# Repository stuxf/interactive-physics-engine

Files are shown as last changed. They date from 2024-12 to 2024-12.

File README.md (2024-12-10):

# Interactive Physics Engine
Final project for Microprocessors (E155) at Harvey Mudd College

The website, and more media can be found at [interactive-physics-engine.netlify.app](https://interactive-physics-engine.netlify.app/).

Authored by https://github.com/Amigoyith and https://github.com/stuxf/

## FPGA

The code for our FPGA is included inside the [/FPGA](/fpga/) folder. The file structure is as seen there.

Some highlihgts are that the main (top-level) module can be found at [/FPGA/main.sv](/fpga/main.sv), the display driver can be found at [/FPGA/display.sv](/fpga/display.sv) and the physics engine can be found at [/FPGA/physics_engine.sv](/fpga/physics_engine.sv).

For the build process, we opted to use [APIO](https://github.com/FPGAwars/apio), an open source ecosystem for FPGA boards using the Yosys toolchain. This allowed us several advantages over Lattice Radiant, including much faster build times. APIO is designed to be very simple to install, the command is just the following:

```BASH
pip3 install apio
```

And this sets up everything you need.

One issue we ran into was that APIO does not support SystemVerilog. We ended up using [github.com/zachjs/sv2v](https://github.com/zachjs/sv2v), combined with APIO, which is why you'll actually see SystemVerilog files in our repository. So our process of uploading our code to our FPGA ended up looking something like this, converting all our SystemVerilog to one big Verilog file, before uploading it to our FPGA.

```BASH
sv2v *.sv > all.v
apio upload
```

## MCU

The code for our MCU is included inside the [/MCU](/MCU/) folder.

The code that describes the MCU's operation is included inside the [main.c](/MCU/main.c) file. The rest of the code is for interacting with our devices, and can be found in [lib](/MCU/lib/). Two of the new libs that we added were for communicating over I2C and with our MPU6050 controller, and their implementation can be found at [lib/MPU6050.c](/MCU/lib/MPU6050.c) and [lib/STM32L432KC_I2C.c](/MCU/lib/STM32L432KC_I2C.c)

## CAD

The CAD for our 3d printed parts is included inside the [/CAD](/CAD/) folder.

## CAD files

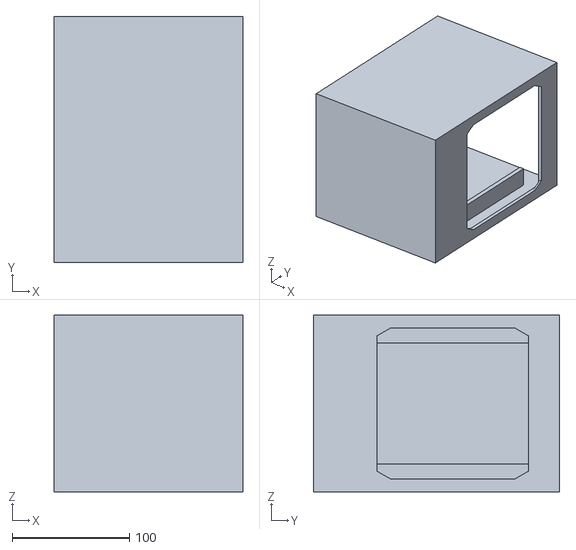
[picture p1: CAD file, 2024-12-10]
CAD/PhysicsEngineContainer.STL
161.0 x 210.0 x 151.0

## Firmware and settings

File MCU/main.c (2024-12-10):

/*
File: main.c
Author: Amy Liu
Email: amyliu01@g.hmc.edu
Date: 12/8/2024
Purpose: Handles all logic to send IMU data to FPGA
*/

#include "STM32L432KC.h"
#include "MPU6050.h"
#include <math.h>
#include <stdio.h>

void mcu_to_fpga(int16_t angle_deg);

int main(void) {

    configureFlash(); // Configure Flash memory for current clock settings.
    configureClock(); // Set up the system clock.
    RCC->APB1ENR1 |= RCC_APB1ENR1_TIM2EN; // Enable TIM2 clock.
    initTIM(TIM2); // Initialize TIM2 timer.
    initI2C(); // Initialize I2C bus.
    initSPI(1, 0, 0); // Initialize SPI with baud rate 1, CPOL=0, CPHA=0.

    uint8_t address = 0x68;  // Example I2C address
    uint8_t reg = 0x6B;      // Power Management Register
    uint8_t writeData = 0x00; // Data to write (e.g., wake up MPU6050)

    MPU6050_ACCEL_t accel_data;
  
    MPU6050_Init();

    while(1){

    MPU6050_Read_Accel(&accel_data);

    // Convert to raw integer data
        int16_t accel_x = (int16_t)(accel_data.Accel_X * 1000); // Convert to milli-g
        int16_t accel_y = (int16_t)(accel_data.Accel_Y * 1000);
        int16_t accel_z = (int16_t)(accel_data.Accel_Z * 1000);

    // Print accelerometer data for debugging
    printf("Accel X: %d, Y: %d, Z: %d\n", accel_x, accel_y, accel_z);

    double angle = atan2(accel_x,accel_y);
    double angle_deg1 = (angle * (180/M_PI));

    // map -180 to + 180 degree to 0 to 360 degree
    if (angle_deg1 < 0){
      angle_deg1+=360;
      }
    angle_deg1 = angle_deg1+(45/2);
    int16_t angle_deg  = (int16_t)angle_deg1 % 360;
    // Send data to FPGA via SPI
    mcu_to_fpga(angle_deg);
    printf("Current facing angle:..%hd", angle_deg);
    delay_millis(TIM2, 500);

}

}

void mcu_to_fpga(int16_t angle_deg) {
    // Set chip enable high
    digitalWrite(SPI_CE, 1);

    // Send accelerometer data (X, Y, Z)
    spiSendReceive((angle_deg >> 8) & 0xFF); // High byte of angle
    spiSendReceive(angle_deg & 0xFF);  

    // Set chip enable low
    digitalWrite(SPI_CE, 0);
}

//Addition debugging function for I2C communication

void testI2C_Write(uint8_t address, uint8_t reg, uint8_t data) {
    printf("Testing I2C Write...\n");
    printf("Writing to Device Address: 0x%X, Register: 0x%X, Data: 0x%X\n", address, reg, data);

    char payload[2] = {reg, data}; // Register address followed by data
    sendI2C(address, payload, 2);

    printf("Write operation completed successfully.\n");
}
void testI2C_Read(uint8_t address, uint8_t reg) {
    printf("Testing I2C Read...\n");
    printf("Reading from Device Address: 0x%X, Register: 0x%X\n", address, reg);

    char regAddress[1] = {reg};
    char readData[1] = {0};

    // First send the register address
    sendI2C(address, regAddress, 1);

    // Then read the data
    readI2C(address, 1, readData);

    printf("Read operation completed successfully. Data: 0x%X\n", readData[0]);
}

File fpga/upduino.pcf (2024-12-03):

# Control Signals
set_io OE     13   # Output Enable
set_io CLK    19   # Clock
set_io LAT    3    # Latch

# Row Select Pins
set_io A      11   # Row address A
set_io B      45   # Row address B
set_io C      18   # Row address C
set_io D      48   # Row address D
set_io E      47   # Row address E

# RGB1 (First set of RGB signals)
set_io R1     4
set_io G1     2
set_io B1     44

# RGB2 (Second set of RGB signals)
set_io R2     6
set_io G2     46
set_io B2     9

# SPI Signals
set_io sdi    10   # Serial Data In
set_io sclk   21   # SPI Clock
set_io led1   38
set_io led2   28
set_io cs_n   20   # Chip Select (active low)
set_io led0   42
set_io resetn 34

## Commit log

2024-11-18 🎉 Setup Repository
2024-11-19 I2C can only sent...
2024-11-19 🎉 FPGA Part Init
2024-11-19 🙈 Ignore Verilog (Not SystemVerilog) files
2024-11-19 🚧 Display Module WIP skeletoning
2024-11-19 🔧 Update Pinout
2024-11-19 ✨ Working Basic Display Driver FSM
2024-11-19 🚧 Sort of broken pixel memory?
2024-11-19 ✨ Diagonal Stripes; Pixel memory working (?)
2024-11-20 corrected working I2C codes
    [main.c]
2024-11-30 🚧 test patterns
2024-12-01 🚧 scuffed bcm
2024-12-02 ✨ BCM WORKS?!??!?
2024-12-02 ✨ 4 bit color! and rainbow!
2024-12-02 ✨ remove clock divider inside display
2024-12-02 SPI working! Display three-axis accl on fpga driven leds.
2024-12-02 🚧 integration part one.
2024-12-02 🚧 coping.
2024-12-03 🔧 new pinout
2024-12-04 🔥 ew outdated pdc file
2024-12-04 🚧 white border
2024-12-04 ♻️ move pattern gen to a seperate module
2024-12-05 ✨ spi code
2024-12-05 SPI code with angle display in 8-axis updated...
2024-12-05 🐛 display off by one bug! caught! stability..,
2024-12-06 ✨ working sand
2024-12-10 CAD added, MCU code organized
    [PhysicsEngineContainer.STL]
2024-12-10 📝 Update FPGA and overall docs
2024-12-10 📝 update docs! :D
